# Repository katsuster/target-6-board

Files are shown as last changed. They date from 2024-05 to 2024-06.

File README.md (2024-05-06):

# target-6-board

`target-6` is an opensource steel targets shooting game.

This is CAD data for I/O board to connect the server board with sensors of steel targets.

Please refer these repositories if you have interest in other modules of `target-6`.

* Client: https://github.com/katsuster/target-6-client
* Server: https://github.com/katsuster/target-6-server

## Requires

* Software
  * KiCad 7.0

## How to use

## Source structures

* ctrl/
  * For controller board
  * Begin or cancel the game by the push button
  * Notify start/end of the game by the beep buzzer
* io/
  * For main board
  * Connect server boards (ex. M5Stamp C3), controller and sensor boards
* sensor/
  * For sensor board
  * Detect the hit of BB bullet on steel plate

## Other documents

* [Parts list](doc/parts_jlcpcb.md)

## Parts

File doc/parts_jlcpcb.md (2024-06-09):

# Parts list

## 2024/06 (tag: 20240610-jlcpcb-order)

Here is a parts list of the 2024/06 order for JLCPCB.

| Parts | Package | Manufacturer | Product | JLCPCB ID |
|--|--|--|--|--|
| Pin header | -- | -- | (Auto) | (Auto) |
| Register | -- | -- | (Auto) | (Auto) |
| Diode(TVS) | SOD-323 | Diodes | SD05-7 | C460454  |
| Diode(Zener) | SOD-123 | Diodes | MMSZ5226B-7-F | C155250  |
| n-MOS | SOT-23 | Onsemi | BSS138 | C52895 |
| RJ14 | Horizontal | Connfly  | DS1133-S40BPX | C77856 |
| USB-A | Horizontal | MOLEX | 67643-3911 | C2765194 |
| USB-C | Horizontal | SHOU HAN | TYPE-C 6P | C456012  |

## 2024/03 (tag: 20240324-jlcpcb-order)

Here is a parts list of the 2024/03 order for JLCPCB.

| Parts | Package | Manufacturer | Product | JLCPCB ID |
|--|--|--|--|--|
| Pin header | -- | -- | (Auto) | (Auto) |
| Register | -- | -- | (Auto) | (Auto) |
| Diode(TVS) | SOD-323 | Diodes | SD05-7 | C460454  |
| Diode(Zener) | SOD-123 | Diodes | MMSZ5226B-7-F | C155250  |
| n-MOS | SOT-23 | Onsemi | BSS123 | C513249  |
| RJ14 | Horizontal | Connfly  | DS1133-S40BPX | C77856 |
| USB-A | Horizontal | MOLEX | 67643-3911 | C2765194 |
| USB-C | Horizontal | SHOU HAN | TYPE-C 6P | C456012  |

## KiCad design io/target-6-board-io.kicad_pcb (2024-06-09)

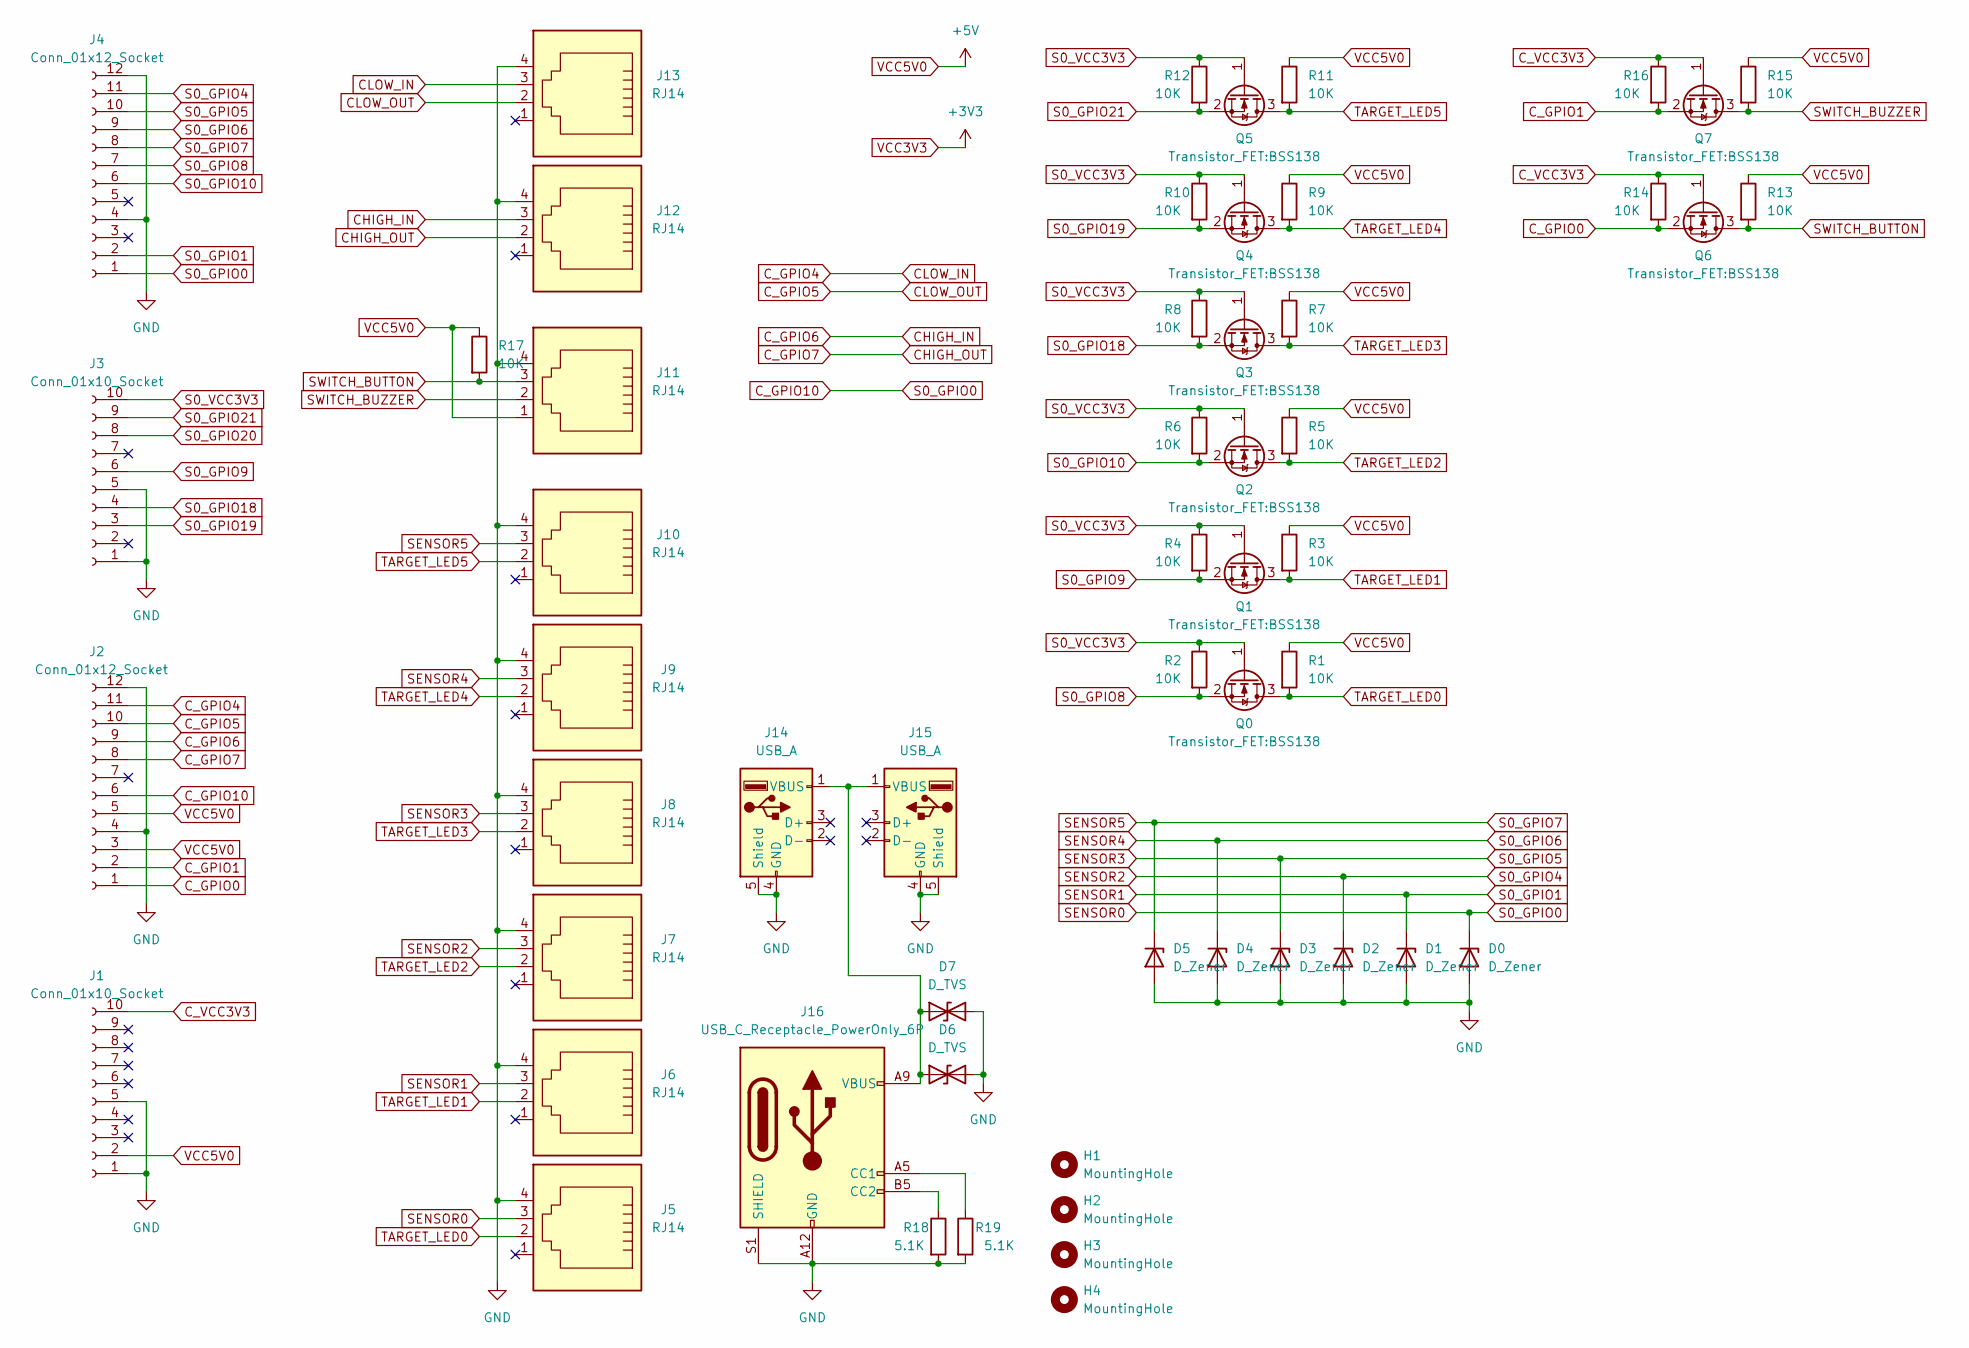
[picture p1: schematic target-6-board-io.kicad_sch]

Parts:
D0, D1, D2, D3, D4, D5: D_Zener; D_SOD-123
D6, D7: D_TVS; D_SOD-323
H1, H2, H3, H4: MountingHole; MountingHole_3.2mm_M3_ISO14580
J1, J3: Conn_01x10_Socket; PinHeader_1x10_P2.54mm_Vertical
J2, J4: Conn_01x12_Socket; PinHeader_1x12_P2.54mm_Vertical
J5, J6, J7, J8, J9, J10, J11, J12, J13: RJ14; RJ14_Connfly_DS1133-S4_Horizontal
J14, J15: USB_A; USB_A_Molex_67643_Horizontal
J16: USB_C_Receptacle_PowerOnly_6P; USB_C_Receptacle_GCT_USB4125-xx-x_6P_TopMnt_Horizontal
Q0, Q1, Q2, Q3, Q4, Q5, Q6, Q7: Transistor_FET:BSS138; SOT-23
R1, R2, R3, R4, R5, R6, R7, R8, R9, R10, R11, R12, R13, R14, R15, R16, R17: 10K; R_0603_1608Metric
R18, R19: 5.1K; R_0603_1608Metric

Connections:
CHIGH_IN: J2.9, J12.3
CHIGH_OUT: J2.8, J12.2
CLOW_IN: J2.11, J13.3
CLOW_OUT: J2.10, J13.2
C_GPIO0: J2.1, Q6.2 (S), R14.2
C_GPIO1: J2.2, Q7.2 (S), R16.2
C_GPIO10: D0.1 (K), J2.6, J4.1, J5.3
C_VCC3V3: J1.10, Q6.1 (G), Q7.1 (G), R14.1, R16.1
GND: D0.2 (A), D1.2 (A), D2.2 (A), D3.2 (A), D4.2 (A), D5.2 (A), D6.2 (A2), D7.2 (A2), J1.1, J1.5, J2.4, J2.12, J3.1, J3.5, J4.4, J4.12, J5.4, J6.4, J7.4, J8.4, J9.4, J10.4, J11.4, J12.4, J13.4, J14.4 (GND), J14.5 (Shield), J15.4 (GND), J15.5 (Shield), J16.A12 (GND), J16.B12 (GND), J16.S1 (SHIELD), R18.2, R19.2
unnamed: D6.1 (A1), D7.1 (A1), J14.1 (VBUS), J15.1 (VBUS), J16.A9 (VBUS), J16.B9 (VBUS)
unnamed: J16.A5 (CC1), R19.1
unnamed: J16.B5 (CC2), R18.1
S0_GPIO1: D1.1 (K), J4.2, J6.3
S0_GPIO4: D2.1 (K), J4.11, J7.3
S0_GPIO5: D3.1 (K), J4.10, J8.3
S0_GPIO6: D4.1 (K), J4.9, J9.3
S0_GPIO7: D5.1 (K), J4.8, J10.3
S0_GPIO8: J4.7, Q0.2 (S), R2.2
S0_GPIO9: J3.6, Q1.2 (S), R4.2
S0_GPIO10: J4.6, Q2.2 (S), R6.2
S0_GPIO18: J3.4, Q3.2 (S), R8.2
S0_GPIO19: J3.3, Q4.2 (S), R10.2
S0_GPIO20: J3.8
S0_GPIO21: J3.9, Q5.2 (S), R12.2
S0_VCC3V3: J3.10, Q0.1 (G), Q1.1 (G), Q2.1 (G), Q3.1 (G), Q4.1 (G), Q5.1 (G), R2.1, R4.1, R6.1, R8.1, R10.1, R12.1
SWITCH_BUTTON: J11.3, Q6.3 (D), R13.2, R17.2
SWITCH_BUZZER: J11.2, Q7.3 (D), R15.2
TARGET_LED0: J5.2, Q0.3 (D), R1.2
TARGET_LED1: J6.2, Q1.3 (D), R3.2
TARGET_LED2: J7.2, Q2.3 (D), R5.2
TARGET_LED3: J8.2, Q3.3 (D), R7.2
TARGET_LED4: J9.2, Q4.3 (D), R9.2
TARGET_LED5: J10.2, Q5.3 (D), R11.2
VCC5V0: J1.2, J2.3, J2.5, J11.1, R1.1, R3.1, R5.1, R7.1, R9.1, R11.1, R13.1, R15.1, R17.1

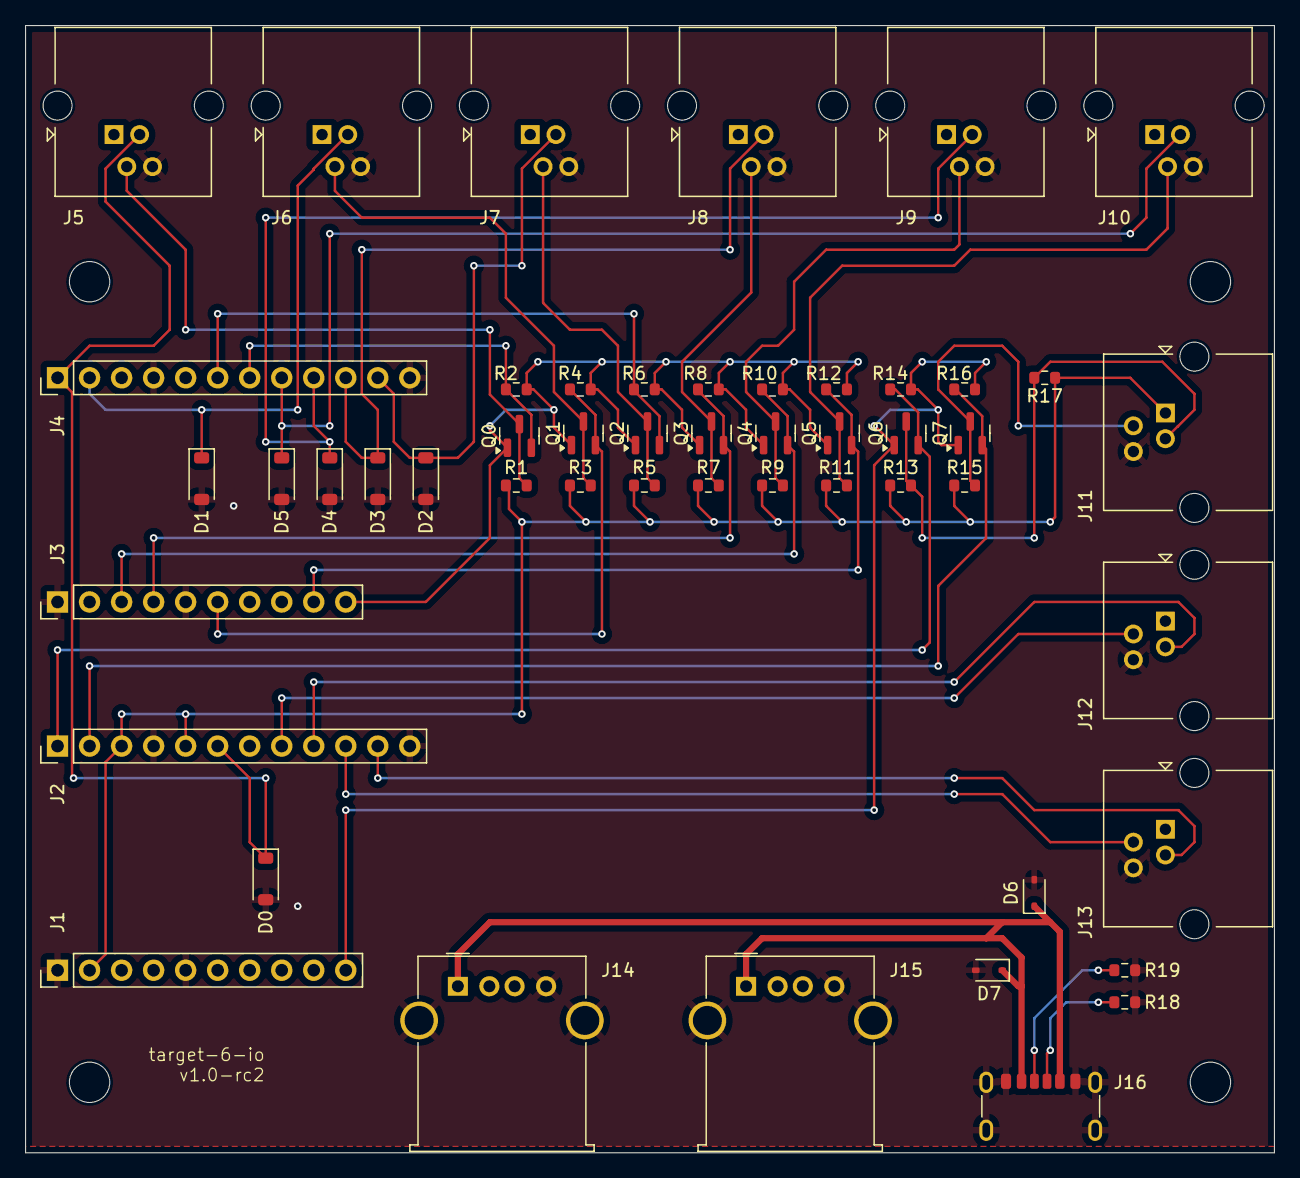
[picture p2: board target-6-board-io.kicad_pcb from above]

Board: 2 copper layers, 99.1 x 89.4 mm, 55 parts (0 on the bottom side), 33 nets.

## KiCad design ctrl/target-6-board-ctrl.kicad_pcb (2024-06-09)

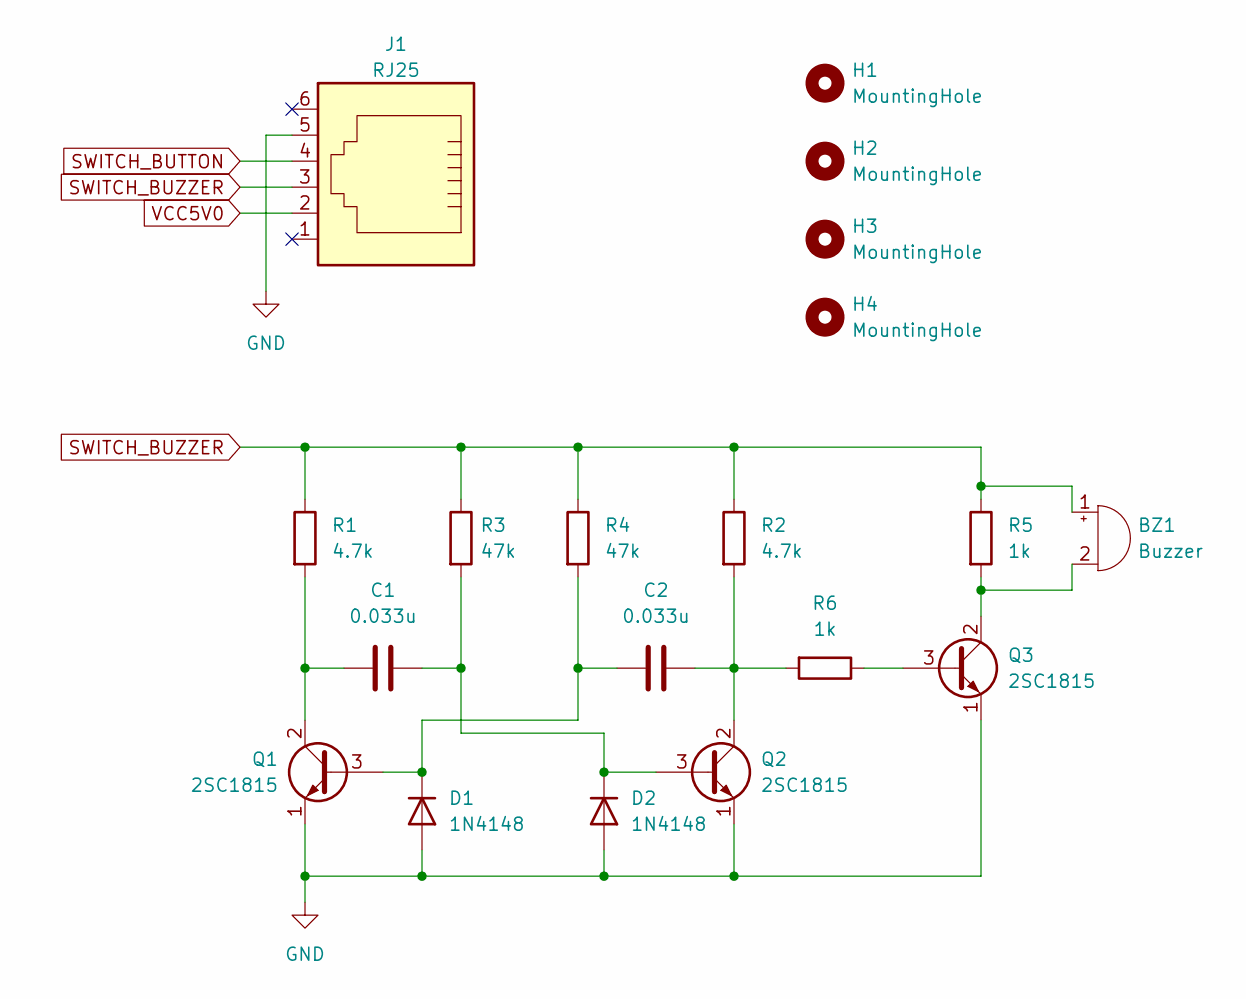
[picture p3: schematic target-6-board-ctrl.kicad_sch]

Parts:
BZ1: Buzzer; Buzzer_15x7.5RM7.6
C1, C2: 0.033u; C_Axial_L5.1mm_D3.1mm_P7.50mm_Horizontal
D1, D2: 1N4148; D_DO-35_SOD27_P7.62mm_Horizontal
H1, H2, H3, H4: MountingHole; MountingHole_3.2mm_M3
J1: RJ25; RJ25_Wayconn_MJEA-660X1_Horizontal
Q1, Q2, Q3: 2SC1815; TO-92_Inline
R1, R2: 4.7k; R_Axial_DIN0207_L6.3mm_D2.5mm_P7.62mm_Horizontal
R3, R4: 47k; R_Axial_DIN0207_L6.3mm_D2.5mm_P7.62mm_Horizontal
R5, R6: 1k; R_Axial_DIN0207_L6.3mm_D2.5mm_P7.62mm_Horizontal

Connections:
GND: D1.2 (A), D2.2 (A), J1.5, Q1.1 (E), Q2.1 (E), Q3.1 (E)
unnamed: BZ1.2 (-), Q3.2 (C), R5.2
unnamed: C2.2, D1.1 (K), Q1.3 (B), R4.2
unnamed: C1.1, D2.1 (K), Q2.3 (B), R3.2
unnamed: C1.2, Q1.2 (C), R1.2
unnamed: C2.1, Q2.2 (C), R2.2, R6.2
unnamed: Q3.3 (B), R6.1
SWITCH_BUTTON: J1.4
SWITCH_BUZZER: BZ1.1 (+), J1.3, R1.1, R2.1, R3.1, R4.1, R5.1
VCC5V0: J1.2

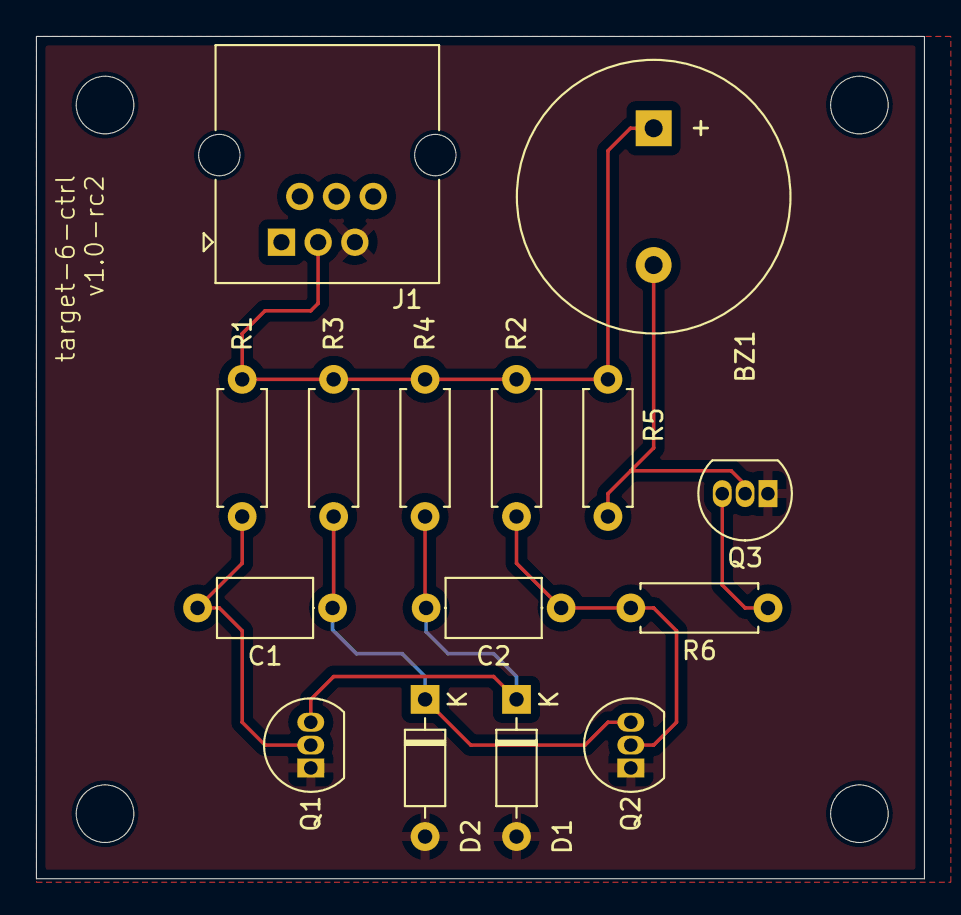
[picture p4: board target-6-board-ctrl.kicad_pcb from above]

Board: 2 copper layers, 49.3 x 46.8 mm, 19 parts (0 on the bottom side), 8 nets.

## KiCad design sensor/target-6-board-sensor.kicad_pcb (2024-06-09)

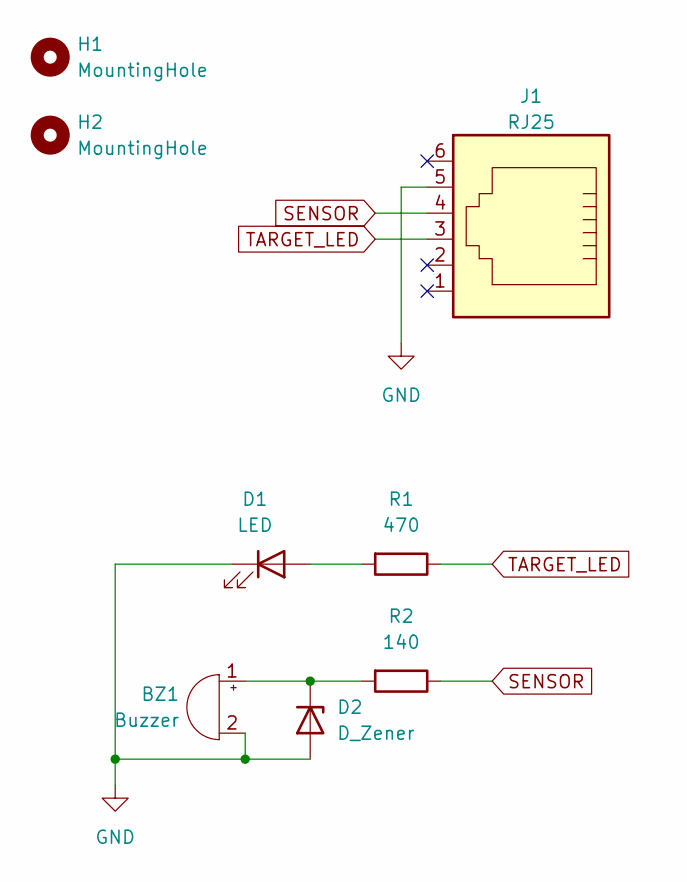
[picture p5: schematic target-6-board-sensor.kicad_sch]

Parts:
BZ1: Buzzer; Buzzer_15x7.5RM7.6
D1: LED; LED_D5.0mm
D2: D_Zener; D_DO-35_SOD27_P7.62mm_Horizontal
H1, H2: MountingHole; MountingHole_2.2mm_M2
J1: RJ25; RJ25_Wayconn_MJEA-660X1_Horizontal
R1: 470; R_Axial_DIN0207_L6.3mm_D2.5mm_P10.16mm_Horizontal
R2: 140; R_Axial_DIN0207_L6.3mm_D2.5mm_P10.16mm_Horizontal

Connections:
GND: BZ1.2 (-), D1.1 (K), D2.2 (A), J1.5
unnamed: BZ1.1 (+), D2.1 (K), R2.2
unnamed: D1.2 (A), R1.2
SENSOR: J1.4, R2.1
TARGET_LED: J1.3, R1.1

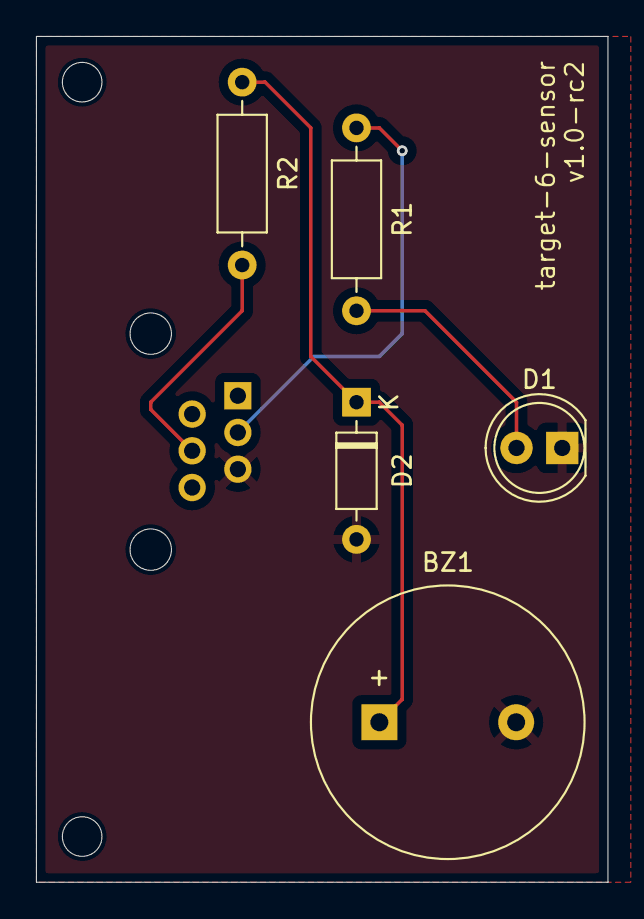
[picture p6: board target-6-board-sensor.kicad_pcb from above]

Board: 2 copper layers, 31.8 x 47.0 mm, 8 parts (1 on the bottom side), 5 nets.

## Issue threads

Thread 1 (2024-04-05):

3.3v to 5v level translation

123swk123, 2024-04-05:
Here is my recommendation for the voltage level translation this will improve the slew rate

for frequency range 100KHz ~ 1MHz and for short wiring length
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

frequency range > 1MHz and for long wiring length
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

123swk123, 2024-04-05:
refer the blow picture, in PCB Gate and Source pins are swapped

bottom left corner is BSS138 spec

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

katsuster, 2024-04-06:
Thanks, fix the mistakes of PCB design in this commit.
https://github.com/katsuster/target-6-board/commit/ab95173e5db8b9afef80bbd365d9a09157b9c615

katsuster, 2024-05-17:
And keep current bidirectional level-shift circuit for future changes.
Thanks for your comment!

Closed 2024-05-17.

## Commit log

2024-03-21 first version
    [target-6-board.kicad_pcb, target-6-board.kicad_sch]
2024-03-24 PCB order version
    - Add USB connectors for power supply to M5Stamp C3
    - Add RJ14 connectors for multiplay
    [target-6-board.kicad_pcb, target-6-board.kicad_sch]
2024-04-05 add no connect flags
    [target-6-board.kicad_pcb, target-6-board.kicad_sch]
2024-04-06 fix NMOS type to BSS138 and PCB design
    [target-6-board.kicad_pcb, target-6-board.kicad_sch]
2024-05-02 io: move I/O boards into io/ directory
    [target-6-board-io.kicad_pcb, target-6-board-io.kicad_sch]
2024-05-02 ctrl: add an empty project
    [target-6-board-ctrl.kicad_pcb, target-6-board-ctrl.kicad_sch]
2024-05-02 sensor: add an empty project
    [target-6-board-sensor.kicad_pcb, target-6-board-sensor.kicad_sch]
2024-05-02 sensor: add first version
    [target-6-board-sensor.kicad_pcb, target-6-board-sensor.kicad_sch]
2024-05-05 sensor: change buzzer to 15mm from 12mm
    [target-6-board-sensor.kicad_pcb, target-6-board-sensor.kicad_sch]
2024-05-17 io: shrink board edge and move mounting holes, pin headers
    [target-6-board-io.kicad_pcb, target-6-board-io.kicad_sch]
2024-05-17 ctrl: add astable multivibrator
    [target-6-board-ctrl.kicad_pcb, target-6-board-ctrl.kicad_sch]
2024-06-05 sensor: fix distance of mounting holes
    [target-6-board-sensor.kicad_pcb, target-6-board-sensor.kicad_sch]
2024-06-09 sensor: add board name and version
    [target-6-board-sensor.kicad_pcb]
2024-06-09 ctrl: add mouting hole and board name and version
    [target-6-board-ctrl.kicad_pcb, target-6-board-ctrl.kicad_sch]
2024-06-09 io: add board name and version
    [target-6-board-io.kicad_pcb]
2026-11-12 update to kicad 10
